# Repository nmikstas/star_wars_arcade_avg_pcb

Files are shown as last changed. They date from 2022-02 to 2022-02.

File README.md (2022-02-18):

# star-wars-arcade-avg-pcb
The source files for the reproduction of the 1983 Star Sars Arcade vector generator PCB. The PCB is designed with Kicad. This project is now complete and verified working!

# Folder Structure
* BOM - Bill of materials for the vector generator PCB
* Gerbers -The gerber files for the vector generator PCB
* pcb - The Kicad design files for the vector generator PCB

# PCB Specifications
* Layers: 2
* Dimensions: 293mm X 525mm
* Different PCB Design: 1
* PCB Thickness: 1.6mm
* Surface Finish: HASL
* Castellated Holes: No
* Copper Weight: 1oz.

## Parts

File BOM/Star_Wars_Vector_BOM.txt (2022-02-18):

Reference                                   Quantity        Value           Part#

A_2                                         1               "LS20"          Jameco 47095
A_3 E_4                                     2               "LS00"          Jameco 46252
A_4 C_4                                     2               "LS157"         Jameco 46771
A_7 BC_8 D_7 BC_9 F_9                       5               "082"           Jamec0 33241
B_3                                         1               "LS174"         Jameco 46931
B_4                                         1               "S129"          Alan-1 state machine ROM
B_7 E_7                                     2               "LF13201"       Digikey DG201BDJ-E3-ND
C_2                                         1               "LS11"          Jameco 46439
C_5 B_5 A_5 F_5 H_5 H_6                     6               "LS194"         Jameco 47052
D_1 C_1 B_1 B_2                             4               "LS161"         Jameco 46818
D_4                                         1               "LS14"          Jameco 46640
D_6 F_8                                     2               "DAC-08"        Digikey DAC0800LCN/NOPB-ND
E_3 E_1 H_3 M_8                             4               "LS02"          Jameco 46287
E_5 F_6                                     2               "LS273"         Jameco 47386
E_6 AB_6                                    2               "AM6012"        Digikey DAC312HPZ-ND
F_1                                         1               "LS27"          Jameco 47378
F_2                                         1               "LS109"         Jameco 46421
F_3                                         1               "S260"          Jameco 64725
F_4                                         1               "LS86"          Jameco 48098
H_2 A_1                                     2               "LS08"          Jamec0 46375
H_4 L_5 L_6 M_5 C_3                         5               "LS175"         Jameco 46957
J_2                                         1               "AVG"           Alan-1 AVG
J_5 E_2                                     2               "LS32"          Jameco 47466
J_6                                         1               "LS10"          Jameco 46404
K_1                                         1               "LS245"         Jameco 47212
K_2 D_3                                     2               "LS42"          Jameco 47773
K_5 D_2 H_1                                 3               "LS74"          Jameco 48004
L_1                                         1               "2732_A"        Jameco 40125
L_3 M_3 P_3 L_4 M_4 P_4                     6               "137211-001"    Jameco 2302575                                          
L_8                                         1               "74LS07"        Jameco 46367
M_1 M_2 N_1 N_2 P_1                         5               "LS244"         Jameco 47183
M_6                                         1               "LS191"         Jameco 47001
N_8                                         1               "LS164"         Jameco 46851
P_5 K_6                                     2               "LS04"          Jameco 46316

C37 C47 C66                                 3               "150pF"         Digikey 399-4213-ND‎
C38                                         1               "39pF"          Digikey 399-4238-ND‎
C4 C21                                      2               ".01uF"         Digikey 399-14040-1-ND‎
C41 C5                                      2               ".01uF"         Digikey 399-4452-1-ND‎
C42                                         1               "10pF"          Digikey 399-14082-ND‎
C43 C44 C46 C81                             4               "100uF"         Digikey 1572-1050-ND‎
C45 C48                                     2               "22uF"          Digikey 1572-1394-ND‎
C8 C25                                      2               ".047uF"        Digikey BC3089-ND‎
C83                                         1               "22pF"          Digikey 1270PH-ND‎
C1 C2 C3 C6 C7 C9 C10 C11 C12 C14           53              ".1uF"          Digikey 399-4454-1-ND
C17 C18 C19 C20 C26 C27 C28 C31 C35 C36
C39 C40 C50 C51 C52 C53 C54 C55 C56 C57
C58 C59 C60 C61 C62 C63 C64 C65 C67 C68
C69 C70 C71 C72 C73 C74 C75 C76 C77 C78
C79 C80 C82  

CR1                                         1               "1N914"         Digikey 1N914FS-ND
CR2                                         1               "LED"           Digikey VAOL-5701SBY4-ND
CR3 CR4                                     2               "1N400"         Digikey 1N4005GP-E3/54

L1 L2 L3                                    3               "1uH"           Digikey M10137-ND‎

Q4 Q5 Q6 Q1 Q7                              5               "2N3904"        Digikey 2N3904-APCT-ND‎
Q8                                          1               "2N3906"        Digikey 2N3906-APCT-ND‎

R44 R41 R71 R68                             4               "10K POT"       Digikey 3386P-103-ND‎
R47 R74                                     2               "2K  POT"       Digikey 3386P-202-ND‎
R88 R92                                     2               "200 POT"       Digikey 3386P-201LF-ND
R26 R27 R54 R55 R14                         5               "820"           Digikey 820QBK-ND‎
R84                                         1               "560"           Digikey 560QBK-ND‎
R87 R91                                     2               "6.19K"         Digikey 6.19KXBK-ND‎
R75 R76                                     2               "1.30K"         Digikey 1.30KXBK-ND‎
R11 R16                                     2               "12K"           Digikey 12KQBK-ND‎
R12                                         1               "24K"           Digikey CF14JT24K0CT-ND‎
R13                                         1               "47K"           Digikey 47KQBK-ND‎
R17                                         1               "6.2K"          Digikey 6.2KQBK-ND‎
R20 R21 R22                                 3               "470"           Digikey 470QBK-ND‎
R23 R24 R25                                 3               "4.7k"          Digikey 4.7KQBK-ND‎
R109 R110 R111 R82 R107                     5               "1K"            Digikey CFR-25JB-52-1K
R42 R69                                     2               "150K"          Digikey 150KQBK-ND‎
R43 R70                                     2               "2.7K"          Digikey S2.7KHCT-ND
R45 R72                                     2               "6.8K"          Digikey CFR-25JB-52-6K8
R46 R73                                     2               "22K"           Digikey FMP100JR-52-22K
R81                                         1               "15K"           Digikey FMP100JR-52-15K
R97                                         1               "3.9K"          Digikey CFR-25JB-52-3K9
R51 R78 R114 R115 R116 R90 R94              7               "100"           Digikey CFR-25JB-52-100R
R30 R31 R58 R106 R95 R96 R85 R86 R89 R93    10              "7.5K"          Digikey 7.50KXBK-ND‎
R98 R99 R100 R101 R102 R103 R104 R105 R15   9               "100K"          Digikey CF14JT100KCT-ND
R1 R2 R3 R4 R5 R6 R7 R8 R9 R10              14              "10K"           Digikey CFR-25JB-52-10K
R83 R112 R113 R117

RV1 RV2                                     2               "VDR"           Alan-1 varistor

VR1                                         1               "L7815_"        Digikey 296-21624-5-ND‎
VR2                                         1               "L7915_"        Digikey 497-7295-5-ND‎

Plastic tabs                                2               "Tabs"          Digikey RPC1553-ND

+15V1 -15V1 +12V1 ~VMEM1 SACLK1 ~VROM1      26              "TP"            Digikey WM6456-ND
~SA1 HALT1 ~INVERTX1 XOUT1 ~INVERTY1
YOUT1 ZREF1 RED1 GREEN1 BLUE1 +5V2
+5V1 GND4 GND3 GND2 GND1 SAEN1 VCTR1
12MHZ1 6MHZ1

Sockets:
8  pin: 5           Jameco 112206
14 pin: 24          Jameco 112214
16 pin: 26          Jameco 112222
20 pin: 10          Jameco 112248
24 pin: 7           Jameco 112264
40 pin: 1           Jameco 112311

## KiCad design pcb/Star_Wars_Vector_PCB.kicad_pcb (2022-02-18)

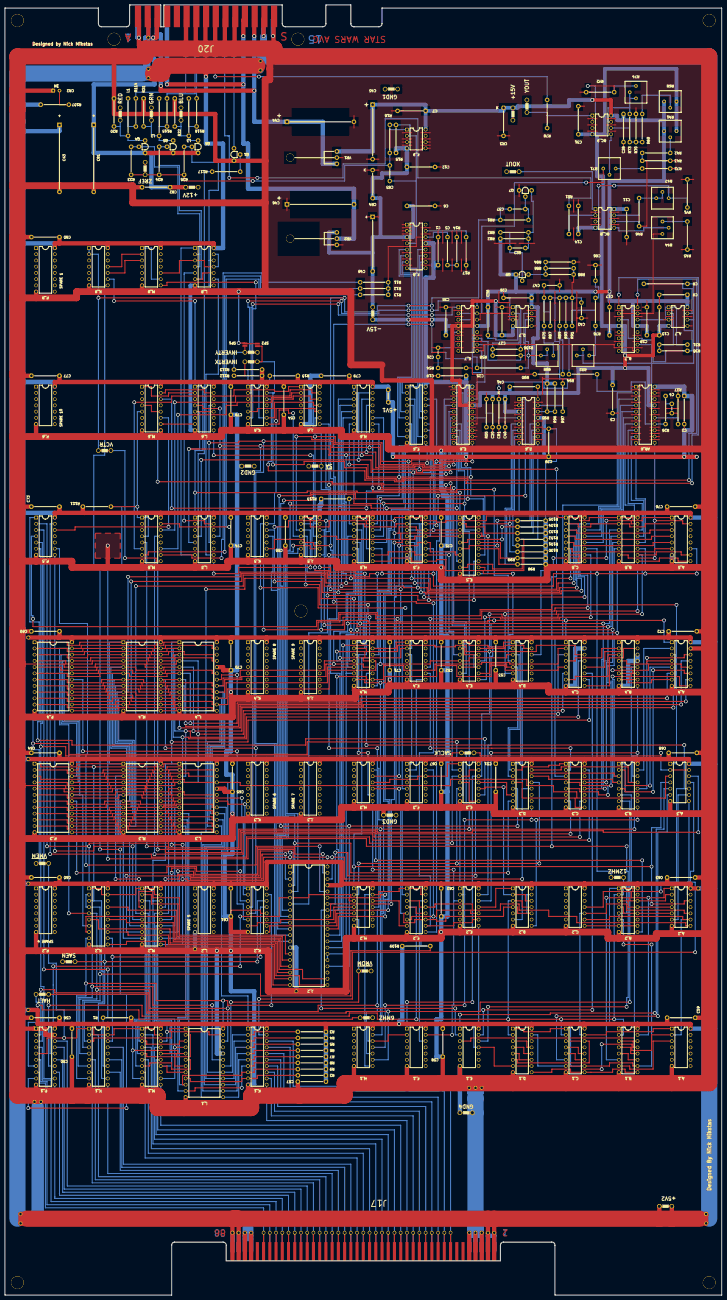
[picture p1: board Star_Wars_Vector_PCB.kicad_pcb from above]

Board: 2 copper layers, 292.1 x 525.8 mm, 340 parts (0 on the bottom side), 330 nets.

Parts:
6MHZ1, 12MHZ1: TP; TEST_POINT
+5V1, +5V2, +12V1: TP; TEST_POINT
+15V1: TP1; TEST_POINT
-15V1: TP; TEST_POINT
AB_6: AM6012; DIP20
A_1: LS08; DIP14
A_2: LS20; DIP14
A_3: LS00; DIP14
A_4: LS157B; DIP16
A_5: LS194; DIP16
A_7: 082; DIP8
BC_8, BC_9: 082; DIP8
BLUE1: TP; TEST_POINT
B_1, B_2: LS161; DIP16
B_3: LS174A; DIP16
B_4: S129; DIP16
B_5: LS194; DIP16
B_7: LF13201; DIP16
C1, C2, C3, C6, C7, C9, C10, C11, C12, C14, C17, C18, C19, C20, C26, C27, C28, C31, C35, C36, C39, C40, C50, C51, C52, C53, C54, C55, C56, C57, C58, C59, C60, C61, C62, C63, C64, C65, C67, C68, C69, C70, C71, C72, C73, C74, C75, C76, C77, C78, C79, C80, C82: .1uF; GenericComp
C4, C21: .01uF; SmallCap
C5, C41: .01uF; GenericComp
C8, C25: .047uF; CapYellow
C37, C47, C66: 150pF; CapBrown
C38: 39pF; CapBrown
C42: 10pF; CapBrown
C43, C44, C46, C81: 100uF; LargeCap
C45, C48: 22uF; CapElec2
C83: 22pF; CapBrown
CR1: 1N914; GenericComp
CR2: LED
CR3, CR4: 1N100; GenericComp
C_1: LS161; DIP16
C_2: LS11; DIP14
C_3: LS175_A; DIP16
C_4: LS157A; DIP16
C_5: LS194; DIP16
D_1: LS161; DIP16
D_2: LS74; DIP14
D_3: LS42; DIP16
D_4: LS14; DIP14
D_6: DAC_8; DIP16
D_7: 082; DIP8
E_1, E_3: LS02; DIP14
E_2: LS32; DIP14
E_4: LS00; DIP14
E_5: LS273A; DIP20
E_6: AM6012; DIP20
E_7: LF13201; DIP16
F_1: LS27; DIP14
F_2: LS109; DIP16
F_3: S260; DIP14
F_4: LS86; DIP14
F_5: LS194; DIP16
F_6: LS273B; DIP20
F_8: DAC_8A; DIP16
F_9: 082; DIP8
GND1, GND2, GND3, GND4: TP; TEST_POINT
GREEN1: TP; TEST_POINT
HALT1: TP; TEST_POINT
H_1: LS74; DIP14
H_2: LS08; DIP14
H_3: LS02; DIP14
H_4: LS175; DIP16
H_5, H_6: LS194; DIP16
J17: Main_Connector; J17
J20: Edge_Connector_30_Pin; J20
J_2: AVG; DDIP40
J_3: Spare7; DIP18
J_4: Spare9; DIP18
J_5: LS32; DIP14
J_6: LS10; DIP14
K_1: LS245; DIP20
K_2: LS42; DIP16
K_3: Spare6; DIP18
K_4: Spare8; DIP18
K_5: LS74; DIP14
K_6: LS04; DIP14
L1, L2, L3: 1uH; Inductor1
L_1: 2732_A; DDIP24
L_2: Spare5; DIP16
L_3, L_4: 137211-001; DDIP24
L_5: LS175C; DIP16
L_6: LS175B; DIP16
L_8: 74LS07; DIP14
M_1, M_2: LS244_B; DIP20
M_3, M_4: 137211-001; DDIP24
M_5: LS175_A; DIP16
M_6: LS191A; DIP16
M_8: LS02; DIP14
N_1: LS244_A; DIP20
N_2: LS244_C; DIP20
N_8: LS164; DIP14
P_1: LS244; DIP20
P_2: Spare4; DIP16
P_3, P_4: 137211-001; DDIP24
P_5: LS04; DIP14
P_6: Spare10; DIP14
P_8: Spare1; DIP16
Q1, Q4, Q5, Q6, Q7: 2N3904; GenericTrans
Q8: 2N3906; GenericTrans
R1, R2, R3, R4, R5, R6, R7, R8, R9, R10, R83, R112, R113, R117: 10K; GenericComp
R11, R16: 12K; GenericComp
R12: 24K; GenericComp
R13: 47K; GenericComp
R14, R26, R27, R54, R55: 820; GenericComp
R15, R98, R99, R100, R101, R102, R103, R104, R105: 100K; GenericComp
R17: 6.2K; GenericComp
R20, R21, R22: 470; GenericComp
R23, R24, R25: 4.7k; GenericComp
R30, R31, R58, R85, R86, R89, R93, R95, R96, R106: 7.5K; GenericComp
R41, R44, R68, R71: 10K; PotBlue
R42, R69: 150K; GenericComp
R43, R70: 2.7K; GenericComp
R45, R72: 6.8K; GenericComp
R46, R73: 22K; GenericComp
R47, R74: 2K; PotBlk
R51, R78, R90, R94, R114, R115, R116: 100; GenericComp
R75, R76: 1.30K; GenericComp
R81: 15K; GenericComp
R82, R109, R110, R111: 1K; GenericComp
R84: 560; GenericComp
R87, R91: 6.19K; GenericComp
R88, R92: 200; PotBlk
R97: 3.9K; GenericComp
R107: 150; GenericComp
RED1: TP; TEST_POINT
RV1, RV2: VDR; GenericComp
Ref**: Val**; VIA_040
Ref**#2, Ref**#3, Ref**#4, Ref**#5, Ref**#6, Ref**#7, Ref**#8, Ref**#9, Ref**#10, Ref**#11, Ref**#12, Ref**#13, Ref**#14, Ref**#15, Ref**#16, Ref**#17, Ref**#18, Ref**#19, Ref**#20, Ref**#21, Ref**#22, Ref**#23, Ref**#24, Ref**#25, Ref**#26, Ref**#27, Ref**#28, Ref**#29, Ref**#30, Ref**#31, Ref**#32, Ref**#33, Ref**#34, Ref**#35, Ref**#36, Ref**#37, Ref**#38, Ref**#39, Ref**#40, Ref**#41, Ref**#42, Ref**#43, Ref**#44, Ref**#45, Ref**#46, Ref**#47, Ref**#48, Ref**#49, Ref**#50, Ref**#51, Ref**#52, Ref**#53, Ref**#54, Ref**#55, Ref**#56, Ref**#57, Ref**#58, Ref**#59, Ref**#60, Ref**#61: Val**; VIA_040
SACLK1: TP; TEST_POINT
SAEN1: TP; TEST_POINT
SP1, SP2: Split_Pad; SplitPad
VCTR1: TP; TEST_POINT
VR1: L7815_; VoltReg
VR2: L7915_; VoltReg
XOUT1: TP; TEST_POINT
YOUT1: TP; TEST_POINT
ZREF1: TP; TEST_POINT

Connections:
3MHZ: N_8.8, P_1.9
12MHZ: 12MHZ1.1, 12MHZ1.2, A_5.11, B_1.2, B_2.2, B_5.11, C_1.2, C_5.11, D_1.2, D_2.3, D_2.11, F_2.4, F_2.12, F_5.11, H_5.11, H_6.11, M_6.14, P_1.14
+5V: +5V1.1, +5V1.2, +5V2.1, +5V2.2, AB_6.20, A_1.14, A_2.14, A_3.14, A_4.16, A_5.16, B_1.16, B_2.16, B_3.16, B_4.16, B_5.16, C1.1, C2.1, C19.1, C39.1, C43.1, C50.1, C51.1, C52.1, C53.1, C54.1, C55.1, C56.1, C57.1, C58.1, C59.1, C60.1, C61.1, C62.1, C63.1, C64.1, C65.1, C67.1, C68.1, C69.1, C70.1, C71.1, C72.1, C73.1, C74.1, C75.1, C76.1, C77.1, C78.1, C79.1, C80.1, C_1.16, C_2.14, C_3.16, C_4.16, C_5.16, D_1.16, D_2.14, D_3.16, D_4.14, D_6.13, E_1.14, E_2.14, E_3.14, E_4.14, E_5.20, E_6.20, F_1.14, F_2.16, F_3.14, F_4.14, F_5.16, F_6.20, F_8.13, H_1.14, H_2.14, H_3.14, H_4.16, H_5.16, H_6.16, J17.1, J17.2, J17.3, J17.4, J17.83, J17.84, J17.85, J17.86, J20.2, J20.14, J20.B, J20.R, J_2.37, J_3.18, J_4.18, J_5.14, J_6.14, K_1.20, K_2.16, K_3.18, K_4.18, K_5.14, K_6.14, L_1.24, L_2.16, L_3.24, L_4.24, L_5.16, L_6.16, L_8.14, M_1.20, M_2.20, M_3.24, M_4.24, M_5.16, M_6.16, M_8.14, N_1.20, N_2.20, N_8.14, P_1.20, P_2.16, P_3.24, P_4.24, P_5.14, P_6.14, P_8.16, R1.1, R2.1, R3.1, R4.1, R5.1, R6.1, R7.1, R8.1, R9.1, R10.2, R107.1, R109.2, R110.2, R111.2, R112.1, R113.1, Ref**.1, Ref**#2.1, Ref**#5.1, Ref**#6.1, Ref**#47.1, Ref**#48.1, Ref**#49.1, Ref**#50.1, Ref**#51.1, Ref**#52.1, Ref**#54.1, Ref**#55.1, Ref**#56.1, Ref**#57.1, Ref**#58.1, Ref**#59.1, Ref**#60.1, Ref**#61.1
+12V: +12V1.1, +12V1.2, C81.1, C82.1, J20.C, Q4.3, Q5.3, Q6.3
+15V: +15V1.1, +15V1.2, A_7.8, BC_8.8, BC_9.8, B_7.13, C7.1, C9.2, C11.2, C18.1, C26.2, C28.2, C36.1, C45.1, CR3.1, D_7.8, E_7.13, F_9.8, Q8.1, R41.1, R68.1, R82.2, R95.1, R96.1, VR1.3
+22VDC: C44.1, J20.3, J20.P, VR1.1
-15V: -15V1.1, -15V1.2, AB_6.17, A_7.4, BC_8.4, BC_9.4, B_7.4, C3.2, C6.1, C10.2, C12.1, C14.2, C17.1, C20.2, C27.2, C31.2, C35.1, C40.1, C41.1, C48.2, CR4.2, D_6.3, D_7.4, E_6.17, E_7.4, F_8.3, F_9.4, R15.2, R41.3, R68.3, VR2.3
-22VDC: C46.2, J20.4, J20.N, VR2.2
AB0: J17.43, J17.44, M_1.6, Ref**#26.1
AB1: J17.35, J17.36, M_1.15, Ref**#30.1
AB2: J17.33, J17.34, M_1.13, Ref**#31.1
AB3: J17.31, J17.32, M_1.11, Ref**#38.1
AB4: J17.45, J17.46, M_1.8, Ref**#25.1
AB5: J17.37, J17.38, M_1.17, Ref**#29.1
AB6: J17.41, J17.42, M_1.4, Ref**#27.1
AB7: J17.39, J17.40, M_1.2, Ref**#28.1
AB8: J17.47, J17.48, N_1.17, Ref**#24.1
AB9: J17.49, J17.50, N_1.15, Ref**#23.1
AB10: J17.51, J17.52, N_1.13, Ref**#22.1
AB11: J17.53, J17.54, N_1.11, Ref**#21.1
AB12: J17.59, J17.60, N_1.8, Ref**#18.1
AB13: J17.55, J17.56, N_1.2, Ref**#20.1
AM0: A_4.13, L_1.8, L_3.8, L_4.8, M_1.14, M_2.14, M_3.8, M_4.8, P_3.8, P_4.8
AM1: A_4.10, L_1.7, L_3.7, L_4.7, M_1.5, M_2.5, M_3.7, M_4.7, P_3.7, P_4.7
AM2: A_4.6, L_1.6, L_3.6, L_4.6, M_1.7, M_2.7, M_3.6, M_4.6, P_3.6, P_4.6
AM3: A_4.3, L_1.5, L_3.5, L_4.5, M_1.9, M_2.9, M_3.5, M_4.5, P_3.5, P_4.5
AM4: C_4.6, L_1.4, L_3.4, L_4.4, M_1.12, M_2.12, M_3.4, M_4.4, P_3.4, P_4.4
AM5: C_4.3, L_1.3, L_3.3, L_4.3, M_1.3, M_2.3, M_3.3, M_4.3, P_3.3, P_4.3
AM6: C_4.13, L_1.2, L_3.2, L_4.2, M_1.16, M_2.16, M_3.2, M_4.2, P_3.2, P_4.2
AM7: C_4.10, L_1.1, L_3.1, L_4.1, M_1.18, M_2.18, M_3.1, M_4.1, P_3.1, P_4.1
AM8: L_1.23, L_3.23, L_4.23, M_3.23, M_4.23, N_1.3, N_2.3, P_3.23, P_4.23
AM9: L_1.22, L_3.22, L_4.22, M_3.22, M_4.22, N_1.5, N_2.5, P_3.22, P_4.22
AM10: L_1.19, L_3.19, L_4.19, M_3.19, M_4.19, N_1.7, N_2.7, P_3.19, P_4.19
AM11: K_2.15, L_1.21, N_1.9, N_2.9
AM12: K_2.14, N_1.12, N_2.14, SAEN1.1, SAEN1.2
AM13: K_2.13, N_1.18, N_2.12
AVG0: J_2.36, P_5.9
AVG1: J_2.39, M_2.15
AVG2: J_2.40, M_2.13
AVG3: J_2.1, M_2.11
AVG4: J_2.2, M_2.8
AVG5: J_2.3, M_2.17
AVG6: J_2.15, M_2.4
AVG7: J_2.16, M_2.2
AVG8: J_2.17, N_2.17
AVG9: J_2.18, N_2.15
AVG10: J_2.19, N_2.13
AVG11: J_2.20, N_2.11
AVG12: J_2.21, N_2.6
AVG13: J_2.22, N_2.8
BLANK: M_8.1, M_8.9
BLUE: J20.8, R116.2
CNTR: E_2.10, F_2.6, F_3.13
DVG0: A_5.6, C_5.6, F_5.6, H_6.6, K_1.9, L_1.9, L_3.9, L_4.9, M_3.9, M_4.9, P_3.9, P_4.9, R2.2
DVG1: A_5.5, C_5.5, F_5.5, H_6.5, K_1.8, L_1.10, L_3.10, L_4.10, M_3.10, M_4.10, P_3.10, P_4.10, R9.2
DVG2: A_5.4, C_5.4, F_5.4, H_6.4, K_1.7, L_1.11, L_3.11, L_4.11, M_3.11, M_4.11, P_3.11, P_4.11, R8.2
DVG3: A_5.3, C_5.3, F_5.3, H_6.3, K_1.6, L_1.13, L_3.13, L_4.13, M_3.13, M_4.13, P_3.13, P_4.13, R7.2
DVG4: B_5.6, C_3.4, H_4.13, H_5.6, K_1.5, L_1.14, L_3.14, L_4.14, M_3.14, M_4.14, P_3.14, P_4.14, R6.2
DVG5: B_5.5, C_3.13, H_4.5, H_5.5, K_1.4, L_1.15, L_3.15, L_4.15, M_3.15, M_4.15, P_3.15, P_4.15, R5.2
DVG6: B_5.4, C_3.5, H_4.12, H_5.4, K_1.3, L_1.16, L_3.16, L_4.16, M_3.16, M_4.16, P_3.16, P_4.16, R4.2
DVG7: B_5.3, C_3.12, H_4.4, H_5.3, K_1.2, L_1.17, L_3.17, L_4.17, M_3.17, M_4.17, P_3.17, P_4.17, R3.2
DVX3: AB_6.11, A_5.15, B_5.7
DVX4: AB_6.10, B_5.12
DVX5: AB_6.9, B_5.13
DVX6: AB_6.8, B_5.14
DVX7: AB_6.7, B_5.15, C_5.7
DVX8: AB_6.6, C_5.12
DVX9: AB_6.5, C_5.13
DVX10: AB_6.4, C_5.14
DVX11: AB_6.3, C_5.15, F_4.10
DVX12: C_3.2, F_4.9
DVY0: E_5.7, F_5.12, F_6.13, J_2.32
DVY1: E_5.4, F_5.13, F_6.14, J_2.31
DVY2: E_5.3, F_5.14, F_6.17, J_2.30
DVY3: E_5.13, E_6.11, F_5.15, F_6.18, H_5.7, J_2.7
DVY4: E_5.8, E_6.10, F_6.3, H_5.12, J_2.8
DVY5: E_5.18, E_6.9, F_6.4, H_5.13, J_2.9
DVY6: E_5.17, E_6.8, F_6.7, H_5.14, J_2.10
DVY7: E_5.14, E_6.7, F_6.8, H_5.15, H_6.7, J_2.11
DVY8: E_6.6, H_6.12, J_2.12, L_5.12, L_6.13
DVY9: E_6.5, H_6.13, J_2.13, L_5.13, L_6.4
DVY10: E_6.4, H_6.14, J_2.29, L_5.5, L_6.5, L_6.12
DVY11: E_6.3, F_4.2, H_6.15, J_2.28, L_5.4
DVY12: F_4.1, H_4.15, J_2.27, J_5.2
E1.5MHZ: J17.75, J17.76, P_1.8, Ref**#37.1
E3MHZ: J17.69, J17.70, P_1.11, Ref**#34.1
E6MHZ: J17.67, J17.68, P_1.13, Ref**#33.1
E12MHZ: J17.73, J17.74, P_1.6, Ref**#36.1
F0: A_4.14, B_3.12
F1: A_4.11, B_3.5
F2: A_4.5, B_3.2
F3: A_4.2, B_3.15
GND: AB_6.1, AB_6.12, AB_6.13, AB_6.19, A_1.7, A_2.7, A_3.7, A_4.8, A_4.15, A_5.7, A_5.8, A_7.3, A_7.5, B_1.8, B_2.8, B_3.8, B_4.8, B_4.13, B_4.14, B_5.8, B_7.5, C1.2, C2.2, C3.1, C4.1, C6.2, C7.2, C9.1, C10.1, C11.1, C12.2, C14.1, C17.2, C18.2, C19.2, C20.1, C21.1, C26.1, C27.1, C28.1, C31.1, C35.2, C36.2, C39.2, C40.2, C42.1, C43.2, C44.2, C45.2, C46.1, C47.1, C48.1, C50.2, C51.2, C52.2, C53.2, C54.2, C55.2, C56.2, C57.2, C58.2, C59.2, C60.2, C61.2, C62.2, C63.2, C64.2, C65.2, C66.1, C67.2, C68.2, C69.2, C70.2, C71.2, C72.2, C73.2, C74.2, C75.2, C76.2, C77.2, C78.2, C79.2, C80.2, C81.2, C82.2, CR1.2, CR2.1, CR3.2, CR4.1, C_1.8, C_2.7, C_3.8, C_4.8, C_4.15, C_5.8, D_1.8, D_2.7, D_3.8, D_4.7, D_6.2, D_7.3, D_7.5, E_1.7, E_2.7, E_3.7, E_4.7, E_5.10, E_6.1, E_6.12, E_6.13, E_6.19, E_7.5, F_1.7, F_2.8, F_3.7, F_4.7, F_5.7, F_5.8, F_6.10, F_8.1, F_8.2, F_9.3, F_9.5, F_9.6, GND1.1, GND1.2, GND2.1, GND2.2, GND3.1, GND3.2, GND4.1, GND4.2, H_1.7, H_2.7, H_3.7, H_4.8, H_5.8, H_6.8, J17.5, J17.6, J17.7, J17.8, J17.9, J17.10, J17.79, J17.80, J17.81, J17.82, J20.1, J20.15, J20.A, J20.F, J20.H, J20.J, J20.K, J20.L, J20.M, J20.S, J_2.14, J_3.9, J_4.9, J_5.7, J_6.7, K_1.10, K_2.8, K_2.12, K_3.9, K_4.9, K_5.7, K_6.7, L_1.12, L_1.20, L_2.8, L_3.12, L_3.20, L_4.12, L_4.20, L_5.8, L_6.8, L_8.7, M_1.10, M_2.10, M_3.12, M_3.20, M_4.12, M_4.20, M_5.8, M_6.8, M_6.9, M_8.7, N_1.10, N_2.10, N_8.7, P_1.1, P_1.10, P_1.19, P_2.8, P_3.12, P_3.20, P_4.12, P_4.20, P_5.7, P_6.7, P_8.8, Q1.1, Q7.1, R14.2, R17.1, R20.1, R21.1, R22.1, R27.1, R43.2, R45.1, R55.1, R70.2, R72.1, R84.1, R97.1, R98.2, R99.2, R100.2, R101.2, R102.1, R103.1, R104.1, R105.1, RV1.2, RV2.2, Ref**#3.1, Ref**#4.1, Ref**#7.1, Ref**#8.1, Ref**#9.1, Ref**#10.1, Ref**#11.1, Ref**#12.1, Ref**#13.1, Ref**#14.1, Ref**#15.1, Ref**#53.1, SP1.1, SP2.1, VR1.2, VR2.1
GO: D_1.7, D_1.10, E_1.11, E_2.8
GREEN: J20.7, R115.2
HALT: B_3.6, HALT1.1, HALT1.2, H_1.9, P_1.2
HALT*: B_3.7, E_1.12
NORM: H_3.12, J_6.9, K_5.9
unnamed: 6MHZ1.1, 6MHZ1.2, P_1.7
unnamed: AB_6.15, R27.2
unnamed: A_1.1, A_2.10, C_1.15, C_2.10
unnamed: A_1.2, A_2.9, C_1.7, C_2.9, D_1.15
unnamed: A_1.3, B_1.7
unnamed: A_2.1, B_1.15, C_2.11
unnamed: A_2.2, B_1.6, B_2.14
unnamed: A_2.4, B_2.3, B_2.13
unnamed: A_2.5, B_2.4, B_2.12
unnamed: A_2.6, A_3.9
unnamed: A_2.13, A_3.8
unnamed: A_3.1, P_5.4
unnamed: A_3.5, E_1.1
unnamed: A_3.6, C_1.6
unnamed: A_4.4, B_4.4
unnamed: A_4.7, B_4.7
unnamed: A_4.9, B_4.6
unnamed: A_4.12, B_4.5
unnamed: A_5.9, B_5.9, D_4.6
unnamed: A_5.10, B_5.10, E_4.8
unnamed: A_7.1, B_7.14, R31.1
unnamed: A_7.2, R30.1, R31.2
unnamed: A_7.7, B_7.3, B_7.11, C8.1, R30.2
unnamed: BC_8.1, BC_8.2, R51.2, XOUT1.1, XOUT1.2
unnamed: BC_8.3, R47.3, RV1.1
unnamed: BC_8.5, R44.2
unnamed: BC_8.6, R42.1, R43.1, R46.2
unnamed: BC_8.7, R46.1, R47.1, R47.2
unnamed: BC_9.1, BC_9.2, R78.2, YOUT1.1, YOUT1.2
unnamed: BC_9.3, R74.3, RV2.1
unnamed: BC_9.5, R71.2
unnamed: BC_9.6, R69.1, R70.1, R73.2
unnamed: BC_9.7, R73.1, R74.1, R74.2
unnamed: BLUE1.1, BLUE1.2, L3.2, Q6.1, R22.2
unnamed: B_1.9, B_2.9, C_1.9, D_1.9, H_3.13
unnamed: B_1.5, B_1.11
unnamed: B_1.4, B_1.12
unnamed: B_1.3, B_1.13
unnamed: B_1.14, E_1.3
unnamed: B_2.7, B_2.10, C_2.8
unnamed: B_3.4, B_4.11, D_3.14
unnamed: B_3.9, D_2.8
unnamed: B_3.13, B_4.12, D_3.15
unnamed: B_3.14, B_4.9, E_2.12
unnamed: B_4.1, C_4.12
unnamed: B_4.2, C_4.4
unnamed: B_4.3, C_4.7
unnamed: B_4.15, C_4.9
unnamed: B_7.1, K_6.12
unnamed: B_7.2, B_7.15, R44.1
unnamed: B_7.16, K_6.13, R112.2, SP2.2
unnamed: C4.2, R26.2
unnamed: C5.1, F_8.14, R11.1, R12.1, R13.1
unnamed: C5.2, R14.1
unnamed: C21.2, R54.2
unnamed: C25.1, D_7.7, E_7.3, E_7.11, R58.2
unnamed: C37.1, Q7.2, R81.1
unnamed: C38.1, Q8.2, R83.1
unnamed: C38.2, Q7.3, R82.1, R83.2
unnamed: C41.2, D_6.16
unnamed: C42.2, CR1.1, D_6.4, R85.1, R86.1, R87.2, R89.2, R91.2, R93.2
unnamed: C47.2, R75.2, R87.1
unnamed: C66.2, R76.2, R91.1
unnamed: C83.2, F_8.4, F_9.2, R15.1, R16.2
unnamed: CR2.2, R107.2
unnamed: C_1.5, C_1.11
unnamed: C_1.4, C_1.12
unnamed: C_1.3, C_1.13
unnamed: C_1.14, D_1.6
unnamed: C_4.11, E_1.13
unnamed: C_5.9, D_4.12
unnamed: C_5.10, E_4.11
unnamed: D_1.5, D_1.11
unnamed: D_1.4, D_1.12
unnamed: D_1.3, D_1.13
unnamed: D_2.1, E_2.11
unnamed: D_2.2, D_2.12, E_3.10
unnamed: D_4.2, F_5.9, H_5.9
unnamed: D_4.4, H_6.9
unnamed: D_6.5, E_5.15, R98.1
unnamed: D_6.6, E_5.16, R99.1
unnamed: D_6.7, E_5.19, R100.1
unnamed: D_6.8, E_5.9, R101.1
unnamed: D_6.9, E_5.12, R102.2
unnamed: D_6.10, E_5.2, R103.2
unnamed: D_6.11, E_5.5, R104.2
unnamed: D_6.12, E_5.6, R105.2
unnamed: D_6.14, R95.2, R96.2
unnamed: D_6.15, R97.2
unnamed: D_7.1, E_7.14, R106.1
unnamed: D_7.2, R58.1, R106.2
unnamed: E_2.3, F_1.13, H_3.8
unnamed: E_3.2, M_6.4, M_6.12
unnamed: E_3.4, E_3.8
unnamed: E_3.3, E_3.13, P_5.13
unnamed: E_4.3, F_5.10, H_5.10
unnamed: E_4.6, H_6.10
unnamed: E_6.15, R55.2
unnamed: E_7.1, K_6.2
unnamed: E_7.2, E_7.15, R71.1
unnamed: E_7.16, K_6.1, R113.2, SP1.2
unnamed: F_1.12, F_2.14
unnamed: F_2.2, H_3.10
unnamed: F_2.7, H_2.12
unnamed: F_3.1, F_4.3
unnamed: F_3.2, F_4.8
unnamed: F_3.5, J_6.10, K_5.13
unnamed: F_6.2, F_8.8
unnamed: F_6.5, F_8.7
unnamed: F_6.6, F_8.6
unnamed: F_6.9, F_8.5
unnamed: F_6.12, F_8.12
unnamed: F_6.15, F_8.11
unnamed: F_6.16, F_8.10
unnamed: F_6.19, F_8.9
unnamed: F_8.15, R17.2
unnamed: GREEN1.1, GREEN1.2, L2.2, Q5.1, R21.2
unnamed: H_2.3, J_2.35
unnamed: H_2.4, K_2.7
unnamed: H_2.5, K_2.9
unnamed: J_2.5, J_5.6
unnamed: J_5.1, J_5.8, J_5.12
unnamed: J_6.1, M_5.6
unnamed: J_6.2, M_5.11
unnamed: J_6.12, K_6.5
unnamed: J_6.13, M_5.14
unnamed: L1.1, R114.1
unnamed: L1.2, Q4.1, R20.2, RED1.1, RED1.2
unnamed: L2.1, R115.1
unnamed: L3.1, R116.1
unnamed: L_5.2, R117.1
unnamed: L_5.7, L_8.1
unnamed: L_5.10, L_8.9
unnamed: L_5.15, L_8.5
unnamed: L_6.2, M_6.1
unnamed: L_6.7, M_6.10
unnamed: L_6.15, M_6.15
unnamed: L_8.2, L_8.4, Q4.2, R23.2
unnamed: L_8.6, L_8.10, Q5.2, R24.2
unnamed: L_8.3, L_8.11, L_8.13, M_8.10
unnamed: L_8.8, L_8.12, Q6.2, R25.2
unnamed: M_2.6, P_5.8
unnamed: M_5.7, R12.2
unnamed: M_5.10, R11.2
unnamed: M_5.15, R13.2
unnamed: M_6.11, P_5.12
unnamed: M_8.2, N_8.11
unnamed: M_8.3, N_8.10
unnamed: N_1.14, P_5.3, R1.2
unnamed: Q1.2, R117.2
unnamed: Q8.3, R84.2, R85.2, R86.2
unnamed: R41.2, R42.2
unnamed: R44.3, R45.2
unnamed: R68.2, R69.2
unnamed: R71.3, R72.2
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

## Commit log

2020-11-29 Added all design files
    [Star_Wars_Vector_PCB-2020-10-02-01-07-59.sch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]
2021-03-24 Updated PCB design and added BOM
    [Star_Wars_Vector_PCB-B_Cu.gbr, Star_Wars_Vector_PCB-B_Mask.gbr, Star_Wars_Vector_PCB-B_SilkS.gbr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]
2021-04-13 Fixed errors on the schematic
    [Star_Wars_Vector_PCB.kicad_pcb, Vector_Sheet_1.sch]
2021-04-14 Updated the gerbers
    [Star_Wars_Vector_PCB-B_Cu.gbr, Star_Wars_Vector_PCB-B_Mask.gbr, Star_Wars_Vector_PCB-B_SilkS.gbr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]
2021-04-17 Fixed the solder mask on J20
    [Star_Wars_Vector_PCB.kicad_pcb]
2022-02-18 Updated test points on pcb and readme file
    [Star_Wars_Vector_PCB-B_Cu.gbr, Star_Wars_Vector_PCB-B_Mask.gbr, Star_Wars_Vector_PCB-B_SilkS.gbr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]
